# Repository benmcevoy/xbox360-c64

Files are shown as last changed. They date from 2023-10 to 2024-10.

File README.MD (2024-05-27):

# XBOX 360 Controller to C64

Try and get a USB 360 controller to work on the c64

xinput support is from https://github.com/Ryzee119/tusb_xinput

DPAD and Right analog stick can be used as joystick.

A is fire.

B is up/jump.

X and Y are autofire.

So far I can read (refer: device.h):

- xbox 360 wireless controller :)
- xbox 360 wired controller 
- generic wired switch controller 
- ps4 ds4
- GP2040-CE ps4, xinput, arcade, gp2040, directinput
- various mice, but as there is no DAC not much we can do with it... yet.  I would like to emulate a CBM 1351.

I cannot read but have on hand to test with:

- GP2040-CE ps3 
- GP2040-CE nintendo 
- real ps3
- 8bitdo ultimate

TODO:

- DONE: read controller via tinyusb
- DONE: dpad is joystick
- DONE: A is fire
- DONE: B is UP
- DONE: Analog stick map to d-pad, with a threshold
- NOPE: Web interface to configure? see the pico fight stick
- NOPE: Analog stick is POTX/POTY - yeah maybe not - got no DAC
- NOPE: X and Y are c64gs secondary fire? - this I can do
- DONE: PS4 controller? yep
- DONE: read controller via tinyusb

Things I wish I had done/done differently...

- connect all C64 pins to GPIO, for the POTX/Y as second buttons 
- use an USB header instead of the pico usb port (as it is a pain and needs an adapter)
- use the waveshare pico or a "stamp" board (it's a lot smaller)
- use the PCB manufacturer to add the transistors and resistors as SMD parts
- and basically get the size down and remove the need for USB A to micro adapter
- analog support, either a digital pot or DAC
- better use of the LED for status
- some way to configure it? not much to configure, but it would be nice.

## prepare

clone with submodules, e,g,

`git clone --recurse-submodules git://github.com/benmcevoy/xbox360-c64`

or you may need to run the below under the pico-sdk folder.

```
cd pico-sdk
git submodule init 
git submodule update
```

export environment variables 
- i use .envrc https://direnv.net/
- or use  ~/.bashrc 
- or whatever

`export PICO_SDK_PATH=/path/to/xbox360-c64/pico-sdk`

## cmake
```
cd ./src/build
# debug build
cmake ../ -DCMAKE_BUILD_TYPE=Debug
```

## make

or use `./build.sh`

```
cd src/build/x360c64
make -j4
```

## build and deploy

```
# make executable
chmod +x ./build.sh
chmod +x ./deploy.sh
chmod +x ./monitor.sh
```

```
# get the picoprobe uf2 https://github.com/raspberrypi/picoprobe
# build, then deploy via picoprobe, then start monitoring UART

./build.sh && ./deploy.sh && ./monitor.sh
```

# Schematic

For USB HID power the Pico via VBUS and not VSYS. VBUS needs power so it can power the controllers.

USB controller is plugged directly into the Pico USB port.  

Thanks to this, https://www.hackster.io/DocSnyderde/connect-usb-joystick-to-commodore-c64-2fb5ba

In the current v02 design power is taken direct from the C64 control port. This mean the USB controller is also being powered from the C64. 

Do not plug in the adapter while the power is on.

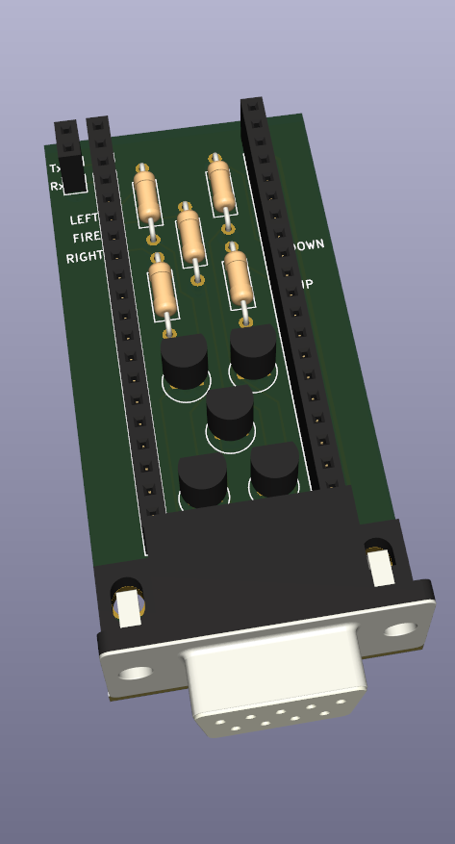
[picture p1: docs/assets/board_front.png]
Board front


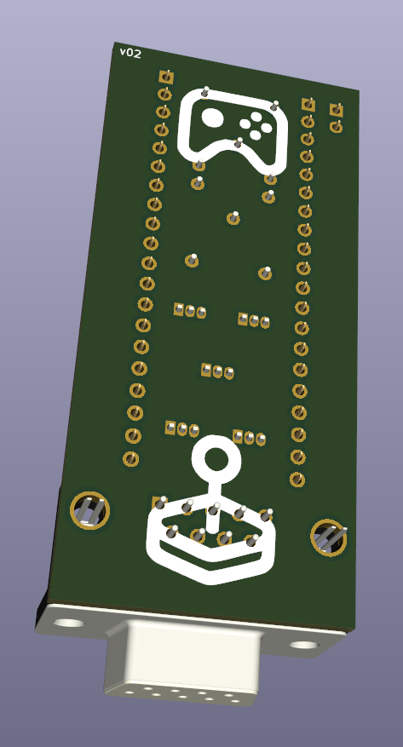
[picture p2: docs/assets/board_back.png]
Board back


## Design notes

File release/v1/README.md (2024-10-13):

# V1

working for PCB version 1.

no mouse support.

B is UP

X or Y is autofire

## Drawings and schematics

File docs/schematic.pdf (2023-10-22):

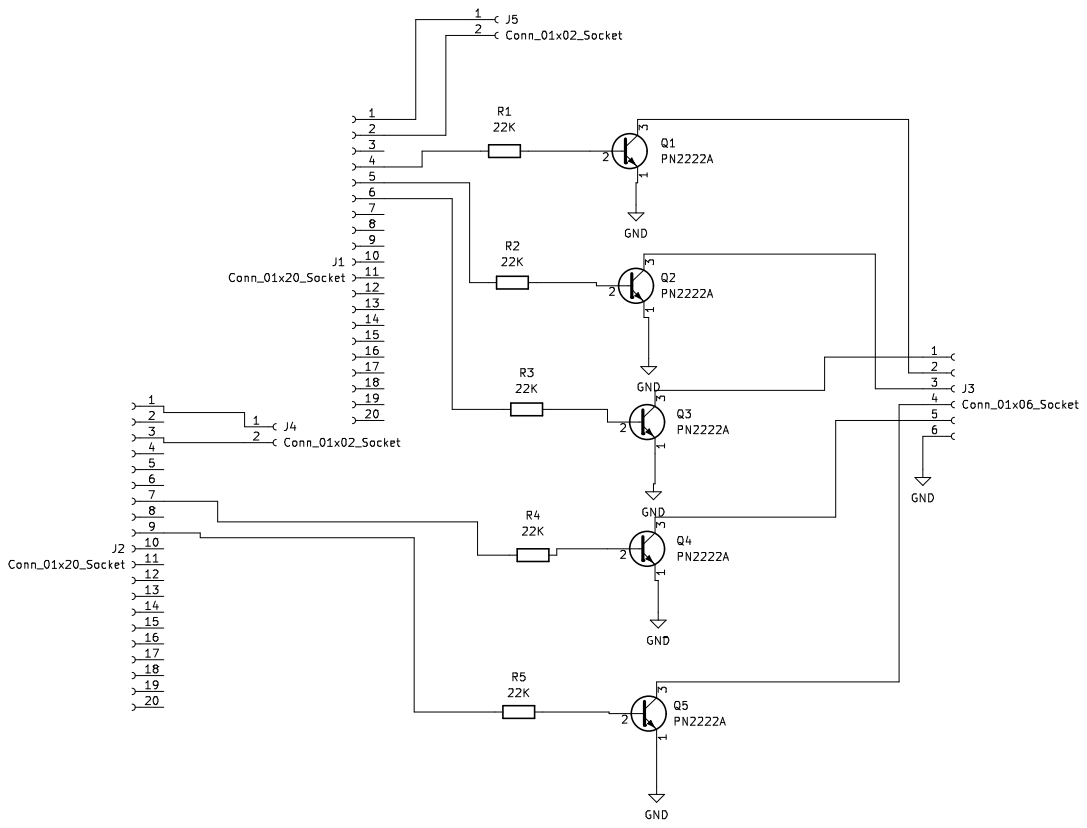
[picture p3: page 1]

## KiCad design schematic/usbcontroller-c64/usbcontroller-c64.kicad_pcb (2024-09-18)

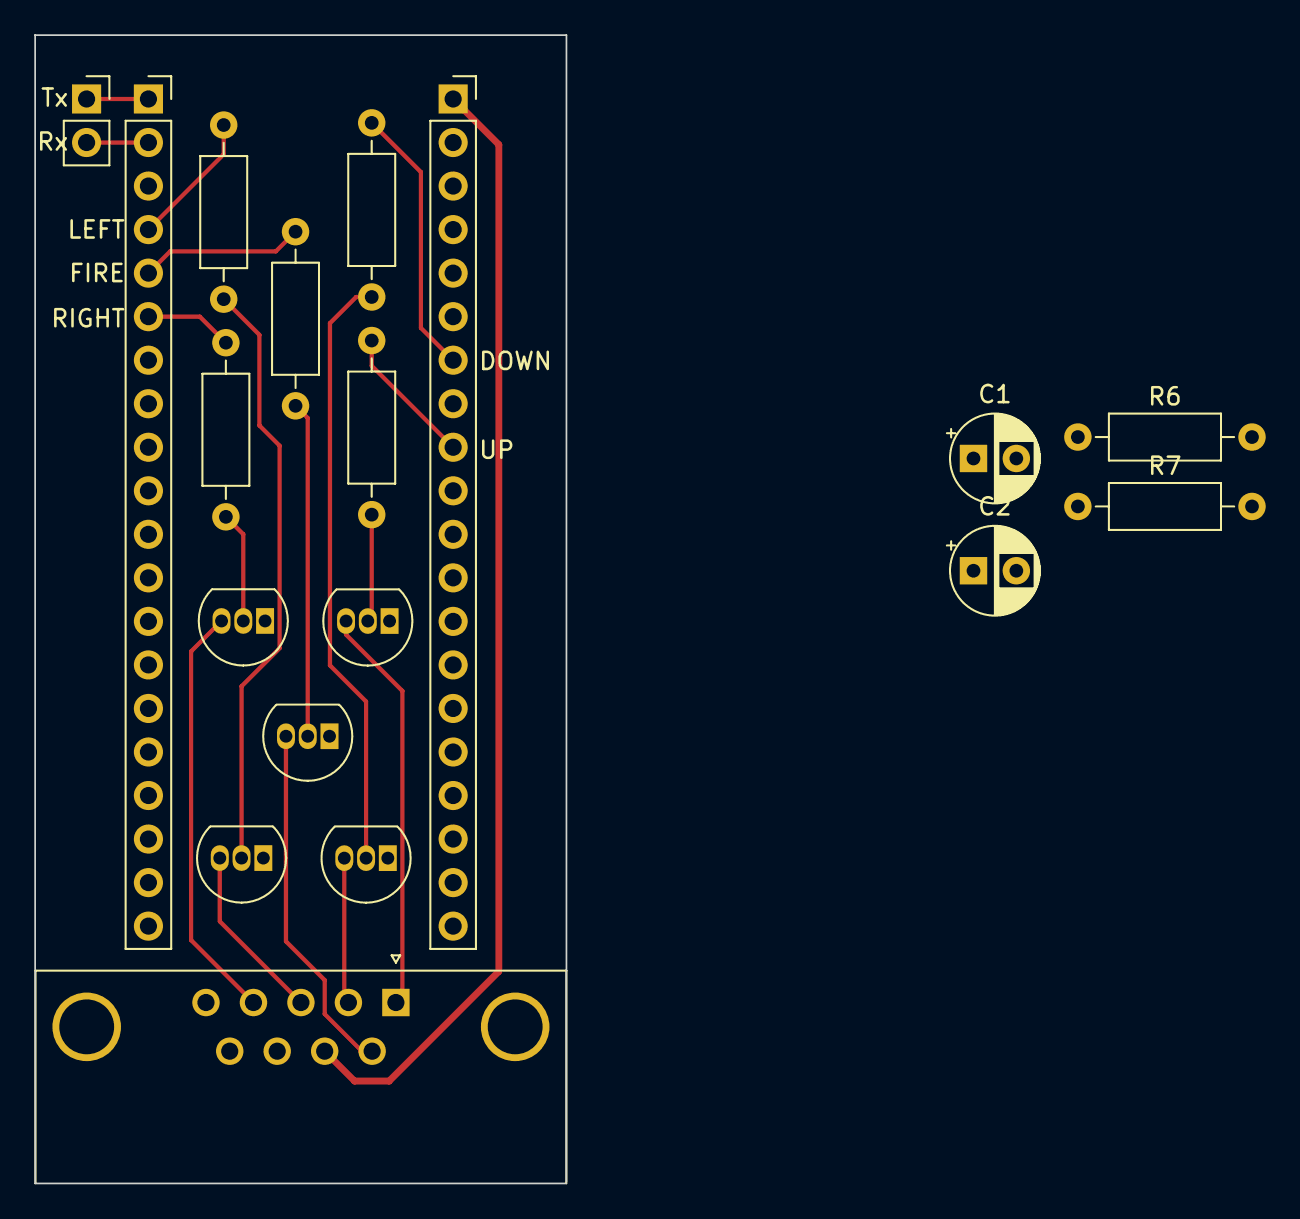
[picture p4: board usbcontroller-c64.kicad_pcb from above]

Board: 2 copper layers, 31.0 x 67.0 mm, 18 parts (0 on the bottom side), 20 nets.

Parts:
C1, C2: 39pF; CP_Radial_D5.0mm_P2.50mm
J1, J2: Conn_01x20_Socket; PinSocket_1x20_P2.54mm_Vertical
J5: Conn_01x02_Socket; PinSocket_1x02_P2.54mm_Vertical
J6: DE9_Receptacle; DSUB-9_Female_Horizontal_P2.77x2.84mm_EdgePinOffset7.70mm_H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
Q1, Q2, Q3, Q4, Q5: PN2222A; TO-92_Inline
R1, R2, R3, R4, R5: 22K; R_Axial_DIN0207_L6.3mm_D2.5mm_P10.16mm_Horizontal
R6, R7: 1K; R_Axial_DIN0207_L6.3mm_D2.5mm_P10.16mm_Horizontal

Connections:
/DOWN: J6.2, Q4.3 (C)
/FIRE: J6.6, Q2.3 (C)
/LEFT: J6.3, Q1.3 (C)
/LOW_POTAX: C2.1, R7.2
/LOW_POTAY: C1.1, R6.2
/RIGHT: J6.4, Q3.3 (C)
/RX: J1.2, J5.2
/TX: J1.1, J5.1
/UP: J6.1, Q5.3 (C)
GND: C1.2, C2.2, J2.3, J6.8, Q1.1 (E), Q2.1 (E), Q3.1 (E), Q4.1 (E), Q5.1 (E)
unnamed: J1.4, R1.1
unnamed: J1.5, R2.1
unnamed: J1.6, R3.1
unnamed: J2.7, R4.1
unnamed: J2.9, R5.1
unnamed: Q1.2 (B), R1.2
unnamed: Q2.2 (B), R2.2
unnamed: Q3.2 (B), R3.2
unnamed: Q4.2 (B), R4.2
unnamed: Q5.2 (B), R5.2

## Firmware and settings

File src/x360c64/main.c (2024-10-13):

#include <stdio.h>
#include <stdlib.h>
#include <string.h>

#include "bsp/board_api.h"
#include "devices/controllercontext.h"
#include "hardware/clocks.h"
#include "hardware/gpio.h"
#include "host/usbh_pvt.h"
#include "pico/bootrom.h"
#include "pico/stdlib.h"
#include "pio_usb.h"
#include "tusb.h"

extern void hid_app_init(JoyPort_t *);

#define X360_PIO_USB_CFG   \
  {14,                     \
   15,                     \
   PIO_SM_USB_TX_DEFAULT,  \
   PIO_USB_DMA_TX_DEFAULT, \
   PIO_USB_RX_DEFAULT,     \
   PIO_SM_USB_RX_DEFAULT,  \
   PIO_SM_USB_EOP_DEFAULT, \
   NULL,                   \
   PIO_USB_DEBUG_PIN_NONE, \
   PIO_USB_DEBUG_PIN_NONE, \
   false,                  \
   PIO_USB_PINOUT_DPDM}

// this is global context
static JoyPort_t *_context;

static int hz = 2000;
static repeating_timer_t _timer;

#define GPIO_LEFT 2
#define GPIO_FIRE 3
#define GPIO_RIGHT 4
#define GPIO_UP 27
#define GPIO_DOWN 28

#define DPAD_N 0
#define DPAD_NE 1
#define DPAD_E 2
#define DPAD_SE 3
#define DPAD_S 4
#define DPAD_SW 5
#define DPAD_W 6
#define DPAD_NW 7

static void debug_context() {
  if (_context->IsConnected == false) return;

  // slow this down to a reasonable level for stdio
  const uint16_t DELAY = 2000;
  static uint16_t delay = DELAY;

  delay--;

  if (delay == 0) {
    delay = DELAY;
    printf(
        "DPAD:%03u A:%03u B:%03u X:%03u Y:%03u POT1_X:%03u POT1_Y:%03u "
        "POT2_X:%03u POT2_Y:%03u",
        _context->dpad, _context->A, _context->B, _context->X, _context->Y,
        _context->POT1_X, _context->POT1_Y, _context->POT2_X, _context->POT2_Y);

    printf("\r\n");
    fflush(stdout);
  }
}

bool auto_firing() {
  // want about 8Hz
  const uint32_t autofire_interval_ms = 120;
  static uint32_t autofire_start_ms = 1000;
  static uint32_t autofire_duty_start_ms = 0;
  static uint32_t autofire_duty_ms = 20;
  static bool is_autofire_duty = false;

  uint32_t now = board_millis();

  bool is_autofire_button_pressed = (_context->X || _context->Y);
  bool is_autofire_interval_elapsed =
      now - autofire_start_ms < autofire_interval_ms;

  if (is_autofire_interval_elapsed) {
    autofire_duty_start_ms = autofire_start_ms + autofire_duty_ms;
    autofire_start_ms += autofire_interval_ms;
    is_autofire_duty = true;
  }

  is_autofire_duty = now - autofire_duty_start_ms < autofire_duty_ms;

  if (is_autofire_duty) return is_autofire_button_pressed && is_autofire_duty;
}

bool sampler_callback(repeating_timer_t *rt) {
  const uint8_t THRESHOLD = 48;

  debug_context();

  bool is_up = (_context->dpad == DPAD_NW) || (_context->dpad == DPAD_N) ||
               (_context->dpad == DPAD_NE) || _context->B ||
               (_context->POT1_Y < THRESHOLD);
  bool is_down = (_context->dpad == DPAD_SE) || (_context->dpad == DPAD_S) ||
                 (_context->dpad == DPAD_SW) ||
                 (_context->POT1_Y > (255 - THRESHOLD));
  bool is_right = (_context->dpad == DPAD_NE) || (_context->dpad == DPAD_E) ||
                  (_context->dpad == DPAD_SE) ||
                  (_context->POT1_X > (255 - THRESHOLD));
  bool is_left = (_context->dpad == DPAD_SW) || (_context->dpad == DPAD_W) ||
                 (_context->dpad == DPAD_NW) ||
                 (_context->POT1_X < (THRESHOLD));

  bool is_auto_firing = auto_firing();

  gpio_put(GPIO_UP, is_up);
  gpio_put(GPIO_DOWN, is_down);
  gpio_put(GPIO_LEFT, is_left);
  gpio_put(GPIO_RIGHT, is_right);
  gpio_put(GPIO_FIRE, is_auto_firing || _context->A);

  return true;
}

void blink_led(bool isConnected) {
  if (isConnected) {
    board_led_write(true);
    return;
  }

  const uint32_t interval_ms = 250;
  static uint32_t start_ms = 0;

  static bool led_state = false;

  // Blink every interval ms
  if (board_millis() - start_ms < interval_ms) return;
  start_ms += interval_ms;

  board_led_write(led_state);
  led_state = 1 - led_state;
}

void context_init() {
  _context = malloc(sizeof(JoyPort_t));

  _context->A = 0;
  _context->B = 0;
  _context->X = 0;
  _context->Y = 0;
  _context->dpad = 8;  // 8 is released
  _context->POT1_X = 128;
  _context->POT1_Y = 128;
  _context->POT2_X = 128;
  _context->POT2_Y = 128;
  _context->IsConnected = false;
}

void sampler_init() {
  // negative timeout means exact delay (rather than delay between callbacks)
  if (!add_repeating_timer_us(-1000000 / hz, sampler_callback, NULL, &_timer)) {
    printf("Failed to add timer\n");
  }
}

void gpio_joyport_init() {
  gpio_init(GPIO_UP);
  gpio_set_dir(GPIO_UP, GPIO_OUT);

  gpio_init(GPIO_DOWN);
  gpio_set_dir(GPIO_DOWN, GPIO_OUT);

  gpio_init(GPIO_LEFT);
  gpio_set_dir(GPIO_LEFT, GPIO_OUT);

  gpio_init(GPIO_RIGHT);
  gpio_set_dir(GPIO_RIGHT, GPIO_OUT);

  gpio_init(GPIO_FIRE);
  gpio_set_dir(GPIO_FIRE, GPIO_OUT);
}

int main(void) {
  set_sys_clock_khz(240000, true);

  stdio_init_all();
  printf("X360C64 started.\r\n");
  sleep_ms(10);

  gpio_joyport_init();
  context_init();
  board_init();

  pio_usb_configuration_t pio_cfg = X360_PIO_USB_CFG;
  tuh_configure(BOARD_TUH_RHPORT, TUH_CFGID_RPI_PIO_USB_CONFIGURATION,
                &pio_cfg);
  tuh_init(BOARD_TUH_RHPORT);

  if (board_init_after_tusb) {
    board_init_after_tusb();
  }

  hid_app_init(_context);
  sampler_init();

  while (1) {
    tuh_task();
    blink_led(_context->IsConnected);
    stdio_flush();
  }

  return 0;
}

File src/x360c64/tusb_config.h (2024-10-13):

/* 
 * The MIT License (MIT)
 *
 * Copyright (c) 2019 Ha Thach (tinyusb.org)
 *
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
 */

#ifndef _TUSB_CONFIG_H_
#define _TUSB_CONFIG_H_

#ifdef __cplusplus
 extern "C" {
#endif

  // CFG_TUSB_DEBUG for debugging - printf to uart
  // 0 : no debug
  // 1 : print error
  // 2 : print warning
  // 3 : print info
#undef CFG_TUSB_DEBUG
#define CFG_TUSB_DEBUG  0

// enable xbox support
#define CFG_TUH_XINPUT 1

// enable PIO USB
#define CFG_TUH_RPI_PIO_USB   0

// RHPort number used for host can be defined by board.mk, default to port 1
#ifndef BOARD_TUH_RHPORT
#define BOARD_TUH_RHPORT      1
#endif

// RHPort max operational speed can defined by board.mk
#ifndef BOARD_TUH_MAX_SPEED
#define BOARD_TUH_MAX_SPEED   OPT_MODE_DEFAULT_SPEED
#endif

//--------------------------------------------------------------------
// COMMON CONFIGURATION
//--------------------------------------------------------------------

// defined by compiler flags for flexibility
#ifndef CFG_TUSB_MCU
#error CFG_TUSB_MCU must be defined
#endif

#ifndef CFG_TUSB_OS
#define CFG_TUSB_OS           OPT_OS_NONE
#endif

#ifndef CFG_TUSB_DEBUG
#define CFG_TUSB_DEBUG        0
#endif

// Enable Host stack, Default is max speed that hardware controller could support with on-chip PHY
#define CFG_TUH_ENABLED       1
#define CFG_TUH_MAX_SPEED     BOARD_TUH_MAX_SPEED


/* USB DMA on some MCUs can only access a specific SRAM region with restriction on alignment.
 * Tinyusb use follows macros to declare transferring memory so that they can be put
 * into those specific section.
 * e.g
 * - CFG_TUSB_MEM SECTION : __attribute__ (( section(".usb_ram") ))
 * - CFG_TUSB_MEM_ALIGN   : __attribute__ ((aligned(4)))
 */
#ifndef CFG_TUSB_MEM_SECTION
#define CFG_TUSB_MEM_SECTION
#endif

#ifndef CFG_TUSB_MEM_ALIGN
#define CFG_TUSB_MEM_ALIGN          __attribute__ ((aligned(4)))
#endif

//--------------------------------------------------------------------
// CONFIGURATION
//--------------------------------------------------------------------

// Size of buffer to hold descriptors and other data used for enumeration
#define CFG_TUH_ENUMERATION_BUFSIZE 400

#define CFG_TUH_HUB                 1 // Enable USB hubs
#define CFG_TUH_CDC                 0
#define CFG_TUH_HID                 (3 * CFG_TUH_DEVICE_MAX) // typical keyboard + mouse device can have 3-4 HID interfaces
#define CFG_TUH_MSC                 0
#define CFG_TUH_VENDOR              0

// max device support (excluding hub device)
#define CFG_TUH_DEVICE_MAX          (CFG_TUH_HUB ? 4 : 1) // hub typically has 4 ports

#ifndef CFG_TUH_MEM_SECTION
#define CFG_TUH_MEM_SECTION
#endif

#ifndef CFG_TUH_MEM_ALIGN
#define CFG_TUH_MEM_ALIGN           __attribute__ ((aligned(4)))
#endif

#ifdef __cplusplus
 }
#endif

#endif /* _TUSB_CONFIG_H_ */

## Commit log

2023-10-22 attempt to make a pcb
    [usbcontroller-c64.kicad_pcb, usbcontroller-c64.kicad_sch]
2023-10-22 add tx/rx for debug
    [usbcontroller-c64.kicad_pcb, usbcontroller-c64.kicad_sch]
2023-10-22 generate drill files
    [usbcontroller-c64-B_Cu.gbr, usbcontroller-c64-B_Mask.gbr, usbcontroller-c64-B_Silkscreen.gbr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]
2023-10-22 zip up for manufacture
    [usbcontroller-c64-job.gbrjob]
2023-10-22 another attempt to make xbobx controller work, but fail
    [xbox_360.h]
2023-10-28 fork pico-sdk so i can make changes
2023-10-29 map buttons to xbox style ABXY
2023-11-26 update schematic to usb db9 connector and power
    [usbcontroller-c64-B_Cu.gbr, usbcontroller-c64-B_Mask.gbr, usbcontroller-c64-B_Silkscreen.gbr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]
2023-12-14 version 2, autofire, direct power
2024-02-25 xbox 360 wireless
2024-02-25 update readme - can read wireless
2024-02-25 update the uf2 for wireless xbox support
2024-03-01 blink LED in a useful way
2024-09-18 remove forked pico-sdk depeancy and get back on the normal one
    [usbcontroller-c64.kicad_pcb, usbcontroller-c64.kicad_sch]
2024-09-19 can now use PIO for USB - currently turned off until I make a PCB
2024-09-19 tweak flashing lights for wireless 360
